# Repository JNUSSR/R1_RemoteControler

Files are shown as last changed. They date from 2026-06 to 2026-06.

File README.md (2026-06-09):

# R1遥控器

R1遥控器的工程仓库，包括PCB工程文件，代码工程文件，外壳文件，使用说明。

- 陶晶驰资料中心：http://wiki.tjc1688.com/
- 固件协议详见：[software/Romote_Controler/README.md](software/Romote_Controler/README.md)

## 更新

**2026-06**: 固件通信协议由自定义二进制帧迁移至 **MAVLink v2**，新增 Web 串口监视器。

```
software/Romote_Controler/
├── mavlink_xml/
│   ├── remote_control.xml   # MAVLink 协议定义 (MsgID=150)
│   └── index.html           # Web 串口监视器
├── Hardware/
│   ├── INTERRUPT/           # MAVLink 打包发送 (替代原 E28 协议)
│   └── mavlink/             # MAVLink C 库
└── README.md                # 详细说明
```

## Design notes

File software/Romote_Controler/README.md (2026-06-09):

# R1 遥控器 · 固件

本目录为 R1 遥控器的 STM32F405 固件工程。原通信协议为自定义二进制帧（E28 模块），现已迁移为标准 **MAVLink v2** 协议。

---

## MAVLink v2 通信协议

### 协议格式

使用 MAVLink v2 帧格式，通过 UART6 (E28 无线模块) 发送，115200/9600 baud 可配置。

### 自定义消息：REMOTE_CONTROL_STATE (MsgID = 150)

| 字段 | 类型 | 偏移 | 说明 |
|---|---|---|---|
| `kfs` | `uint32_t` | 0 | 梅林 KFS 按键矩阵 4×3，每元素 2 bit（值 0~3），共 24 bit |
| `encoder_0` | `int16_t` | 4 | 编码器 0 旋转位置值 |
| `encoder_1` | `int16_t` | 6 | 编码器 1 旋转位置值 |
| `encoder_2` | `int16_t` | 8 | 编码器 2 旋转位置值 |
| `encoder_3` | `int16_t` | 10 | 编码器 3 旋转位置值 |
| `move_0` | `int16_t` | 12 | 摇杆通道 0 移动量 |
| `move_1` | `int16_t` | 14 | 摇杆通道 1 移动量 |
| `move_2` | `int16_t` | 16 | 摇杆通道 2 移动量 |
| `move_3` | `int16_t` | 18 | 摇杆通道 3 移动量 |
| `mode` | `uint8_t` | 20 | 4 路模式拨码开关，bit0~bit3 对应 mode[0]~mode[3]（0=拨下，1=未拨下） |
| `act` | `uint8_t` | 21 | 6 动作独立位掩码：bit0~2=动作1~3(双稳态)，bit3~5=动作4~6(瞬时)，bit6~7保留 |
| `kfs_put` | `uint8_t` | 22 | R2 九宫格按键矩阵 2×3，每元素 1 bit（值 0~1），共 6 bit |

**Payload 大小**: 23 字节（MAVLink v2 会裁剪末尾零字节，实际传输长度可变 ≤23）

### 屏幕值到协议值的映射

**kfs（梅林矩阵 4×3）**:

| 屏幕上报 | 含义 | 减 1 后 | 协议存储 (2 bit) |
|---|---|---|---|
| 1 | 空 | 0 | `00` |
| 2 | R1 | 1 | `01` |
| 3 | R2 | 2 | `10` |
| 4 | 假 | 3 | `11` |

**kfs_put（九宫格 2×3）**:

| 屏幕上报 | 含义 | 减 1 后 | 协议存储 (1 bit) |
|---|---|---|---|
| 1 | 不放 | 0 | `0` |
| 2 | 放 | 1 | `1` |

**act（动作指令）**，6 个动作独立位掩码，互不干扰：

| Bit | 动作 | 含义 | 行为 |
|---|---|---|---|
| bit0 | 动作1 | 0=释放, 1=按下 | **双稳态**，不清零，状态持续上报 |
| bit1 | 动作2 | 0=释放, 1=按下 | **双稳态**，不清零，状态持续上报 |
| bit2 | 动作3 | 0=释放, 1=按下 | **双稳态**，不清零，状态持续上报 |
| bit3 | 动作4 | 0=空闲, 1=触发 | **瞬时**，发送后自动清零 |
| bit4 | 动作5 | 0=空闲, 1=触发 | **瞬时**，发送后自动清零 |
| bit5 | 动作6 | 0=空闲, 1=触发 | **瞬时**，发送后自动清零 |
| bit6~7 | — | 保留 | — |

> 屏幕上报原始值 `0xXY`（X=1~6, Y=1松开/2按下），固件解码后置位/清除 act_state 对应 bit。
> 可同时按下动作1和动作2，act=0x03，两个状态独立保留。

### KFS 位打包规则

```
kfs (uint32_t, bit[23:0]):
  kfs[0][0] → bit[ 1: 0]    kfs[2][0] → bit[13:12]
  kfs[0][1] → bit[ 3: 2]    kfs[2][1] → bit[15:14]
  kfs[0][2] → bit[ 5: 4]    kfs[2][2] → bit[17:16]
  kfs[1][0] → bit[ 7: 6]    kfs[3][0] → bit[19:18]
  kfs[1][1] → bit[ 9: 8]    kfs[3][1] → bit[21:20]
  kfs[1][2] → bit[11:10]    kfs[3][2] → bit[23:22]
  bit[31:24] → 保留

kfs_put (uint8_t, bit[5:0]):
  kfs_put[0][0] → bit[0]    kfs_put[1][0] → bit[3]
  kfs_put[0][1] → bit[1]    kfs_put[1][1] → bit[4]
  kfs_put[0][2] → bit[2]    kfs_put[1][2] → bit[5]
  bit[7:6] → 保留
```

### 发送条件

- **硬守卫**: E28 模块空闲 (PB15 引脚 = HIGH)
- **软守卫**: STM32 UART6 DMA 发送就绪 (`huart6.gState == HAL_UART_STATE_READY`)
- **模式条件**: 仅当 `mode[0]` 拨下（低电平）时发送

### 发送后消费

- **kfs / kfs_put**: 保持屏幕上报的最新值，**发送后不清零**，持续上报当前状态
- **act**: 固件内部维护 `act_state` 位掩码（static 变量）
  - 屏幕上报 `0xXY` 事件 → 解码 ID/状态 → 置位/清除 act_state 对应 bit → 屏幕 `act` 清零消费
  - 动作 1~3 (bit0~2)：**双稳态**，按下置位、松开清零，不清除
  - 动作 4~6 (bit3~5)：**瞬时**，按下置位，发送后 `act_state &= ~0x38` 自动清零
  - 6 个动作独立保存，同时按下多个互不干扰

---

## 目录结构

```
software/Romote_Controler/
├── Core/                    # STM32CubeMX 生成的核心代码
│   ├── Inc/
│   │   └── main.h
│   └── Src/
│       ├── main.c           # 主程序，printf → USART2 串口屏
│       ├── syscalls.c       # newlib/picolibc 系统调用 (printf 重定向)
│       └── ...
├── Hardware/
│   ├── E28/                 # E28 模块旧驱动 (已弃用，保留参考)
│   │   └── e28.c
│   ├── INTERRUPT/           # 中断处理
│   │   ├── interrupt.c      # TIM5 中断回调 + MAVLink 打包发送
│   │   └── interrupt.h
│   ├── SCREEN/              # 触摸屏驱动 (USART2)
│   │   ├── screen.c         # 屏幕数据解析 (HAL_UARTEx_RxEventCallback)
│   │   └── screen.h
│   ├── ENCODER/             # 编码器读取
│   ├── ADC_GET/             # ADC 摇杆数据采集
│   ├── INIT/                # 系统初始化
│   └── mavlink/             # MAVLink C 库 (从 XML 生成)
│       ├── mavlink_types.h
│       ├── mavlink_helpers.h
│       └── remote_control/
│           ├── mavlink.h
│           └── mavlink_msg_remote_control_state.h
├── mavlink_xml/
│   ├── remote_control.xml   # MAVLink 协议定义 (dialect XML)
│   └── index.html           # Web 串口监视器 (Chrome/Edge)
├── CMakeLists.txt
└── README.md
```

---

## 更新日志

### 2026-06 — MAVLink v2 协议迁移

| 变更 | 文件 | 说明 |
|---|---|---|
| 新增 | `mavlink_xml/remote_control.xml` | MAVLink v2 协议定义，消息 ID=150 |
| 新增 | `mavlink_xml/index.html` | 网页版 MAVLink 串口监视器 (Web Serial API) |
| 新增 | `Hardware/mavlink/` | 从 XML 生成的 MAVLink C 库 |
| 修改 | `Hardware/INTERRUPT/interrupt.c` | 新增 `MAVLink_Pack_And_Send()` 替代原 `Pack_And_Send_E28()` |
| 修改 | `Hardware/INTERRUPT/interrupt.h` | 更新依赖：`e28.h` → `mavlink.h` |
| 修改 | `Core/Src/main.c` | 新增 `__io_putchar()` 修复 GCC 下 printf 重定向 |

**数据精度优化**:
- `kfs[4][3]`: 12 字节 → 4 字节（uint32_t 位压缩，每元素 2 bit）
- `kfs_put[2][3]`: 6 字节 → 1 字节（uint8_t 位压缩，每元素 1 bit）
- `mode[4]`: 新增，1 字节（4 bit）
- 总 payload: 37 字节 → **23 字节**

**关键修复**:
- 修复 DMA 发送缓冲区栈内存生命周期问题 (改为 static/全局)
- 修复 `mavlink_message_t`(~295B) 在 ISR 栈分配导致栈溢出
- 修复 GCC/newlib 工具链 `printf` 缺少 `__io_putchar()` 实现

---

## Web 监视器使用

1. 用 Chrome/Edge 浏览器打开 `mavlink_xml/index.html`
2. 选择对应 COM 口和波特率，点击「连接串口」
3. 遥控器 `mode[0]` 拨下后，页面实时更新所有数据

---

## 构建

```bash
cd software/Romote_Controler
cmake -B build -G "Unix Makefiles"  # 或 Ninja
cmake --build build
```

工具链: `arm-none-eabi-gcc` (STM32CubeIDE / GNU Arm Embedded Toolchain)

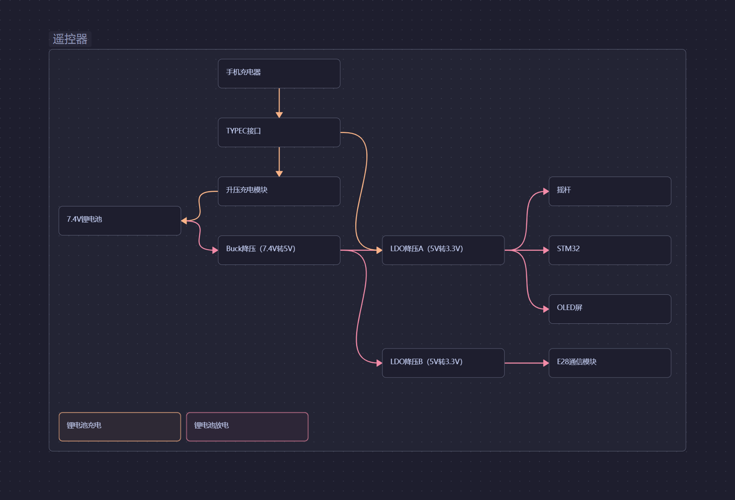
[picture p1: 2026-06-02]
hardware/R1遥控器电路框架.png

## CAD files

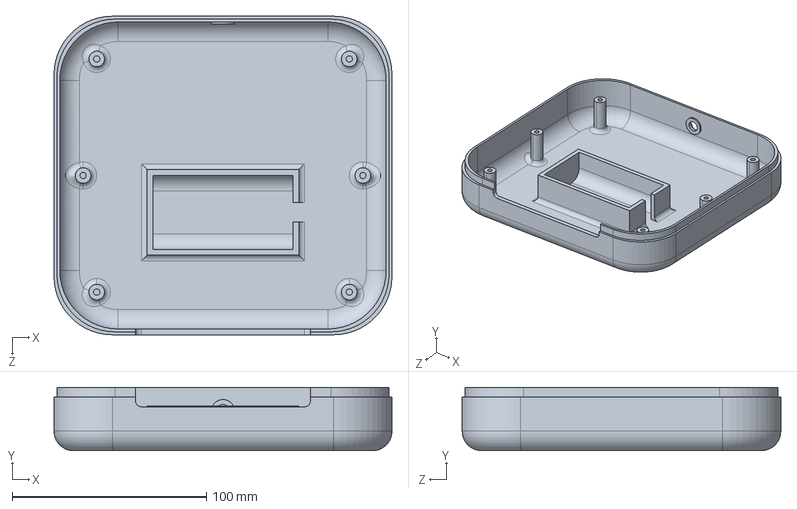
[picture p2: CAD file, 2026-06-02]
structure/外壳/遥控器外壳底板.STEP
174.0 x 32.6 x 164.0 mm

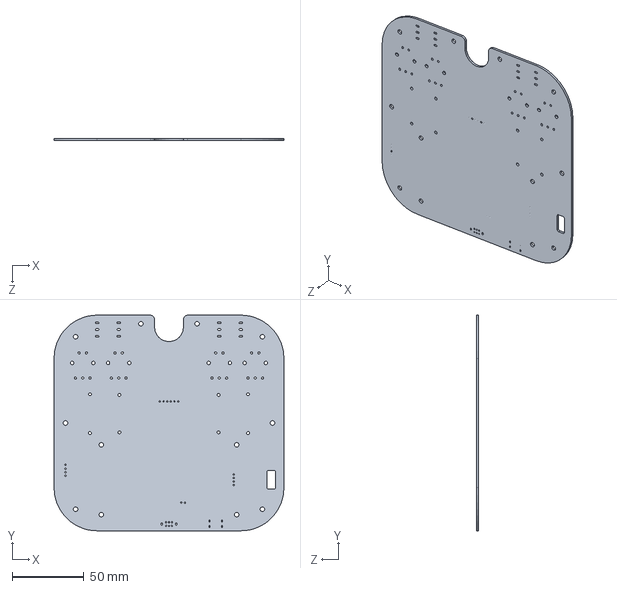
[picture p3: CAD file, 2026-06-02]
structure/外壳/遥控器PCB.SLDPRT
160.0 x 150.0 x 1.60 mm

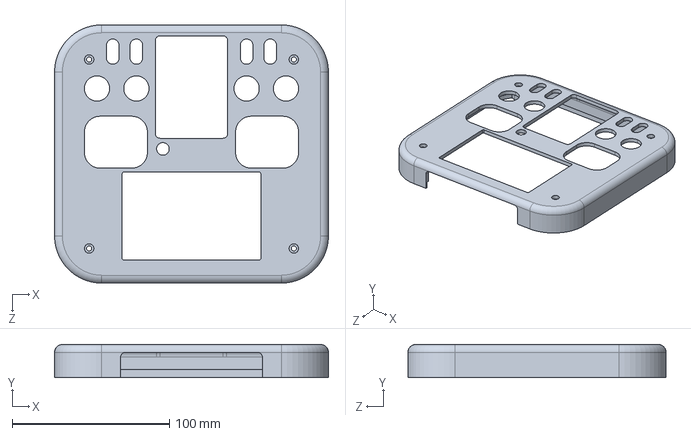
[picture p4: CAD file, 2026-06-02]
structure/外壳/遥控器外壳顶板.STEP
174.0 x 21.0 x 164.0 mm

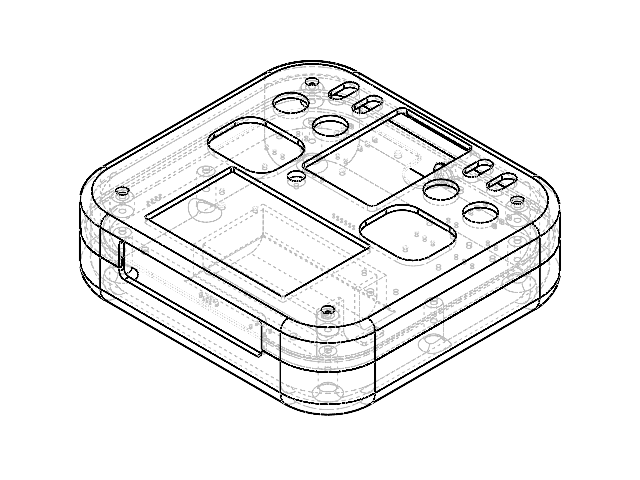
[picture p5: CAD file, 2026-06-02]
structure/外壳/遥控器装配.SLDASM
遥控器外壳底板
遥控器外壳顶板
遥控器PCB

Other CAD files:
structure/外壳/遥控器外壳底板.SLDPRT
structure/外壳/遥控器外壳顶板.SLDPRT

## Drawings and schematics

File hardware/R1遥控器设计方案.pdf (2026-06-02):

## R1遥控器设计方案 一、操作方案

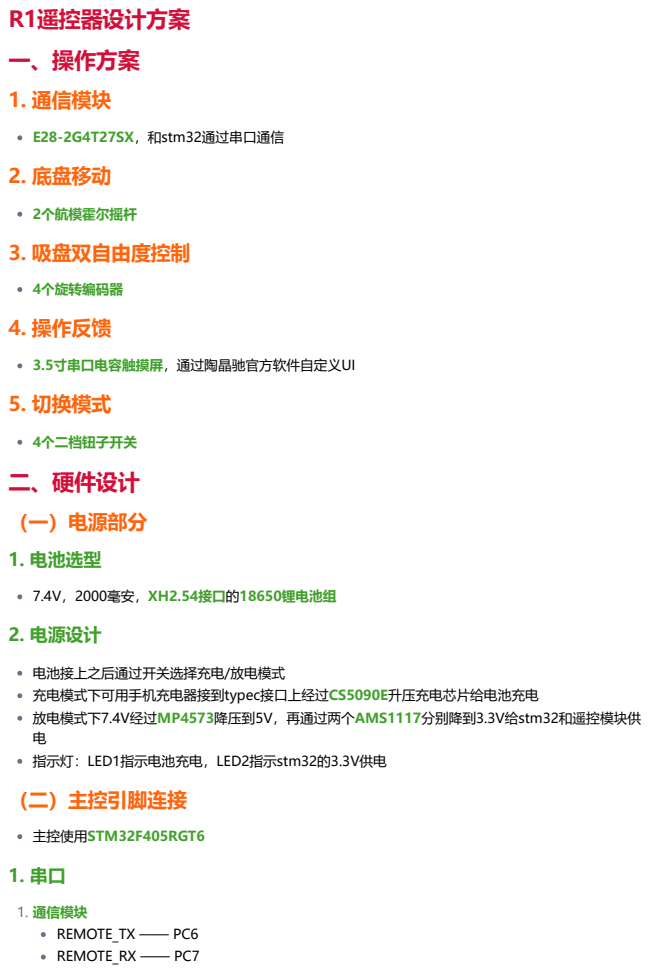
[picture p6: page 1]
1. 通信模块; 2. 底盘移动; 3. 吸盘双自由度控制; 4. 操作反馈; 5. 切换模式; 二、硬件设计; （一）电源部分; 1. 电池选型; 2. 电源设计; （二）主控引脚连接; E28-2G4T27SX，和stm32通过串口通信; 2个航模霍尔摇杆; 4个旋转编码器; 3.5寸串口电容触摸屏，通过陶晶驰官方软件自定义UI; 4个二档钮子开关; 7.4V，2000毫安，XH2.54接口的18650锂电池组; 电池接上之后通过开关选择充电/放电模式 充电模式下可用手机充电器接到typec接口上经过CS5090E升压充电芯片给电池充电 放电模式下7.4V经过MP4573降压到5V，再通过两个AMS1117分别降到3.3V给stm32和遥控模块供 电 指示灯：LED1指示电池充电，LED2指示stm32的3.3V供电; 主控使用STM32F405RGT6; 1. 通信模块 REMOTE_TX —— PC6 REMOTE_RX —— PC7

### 2. ADC

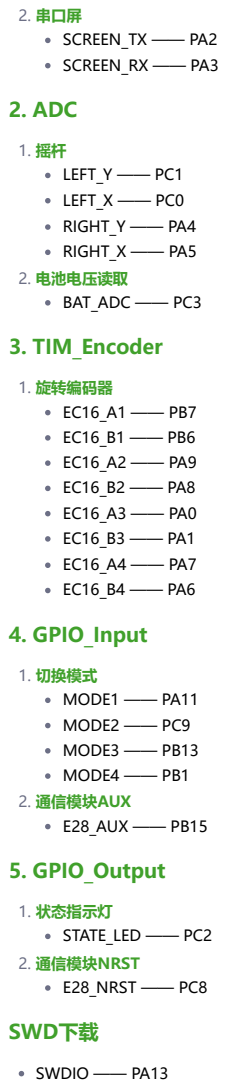
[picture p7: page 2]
3. TIM_Encoder; 4. GPIO_Input; 5. GPIO_Output; SWD下载; 2. 串口屏 SCREEN_TX —— PA2 SCREEN_RX —— PA3; 1. 摇杆 LEFT_Y —— PC1 LEFT_X —— PC0 RIGHT_Y —— PA4 RIGHT_X —— PA5 2. 电池电压读取 BAT_ADC —— PC3; 1. 旋转编码器 EC16_A1 —— PB7 EC16_B1 —— PB6 EC16_A2 —— PA9 EC16_B2 —— PA8 EC16_A3 —— PA0 EC16_B3 —— PA1 EC16_A4 —— PA7 EC16_B4 —— PA6; 1. 切换模式 MODE1 —— PA11 MODE2 —— PC9 MODE3 —— PB13 MODE4 —— PB1 2. 通信模块AUX E28_AUX —— PB15; 1. 状态指示灯 STATE_LED —— PC2 2. 通信模块NRST E28_NRST —— PC8; SWDIO —— PA13

SWCLK —— PA14

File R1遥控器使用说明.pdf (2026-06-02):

## R1遥控器使用说明 一、遥控器

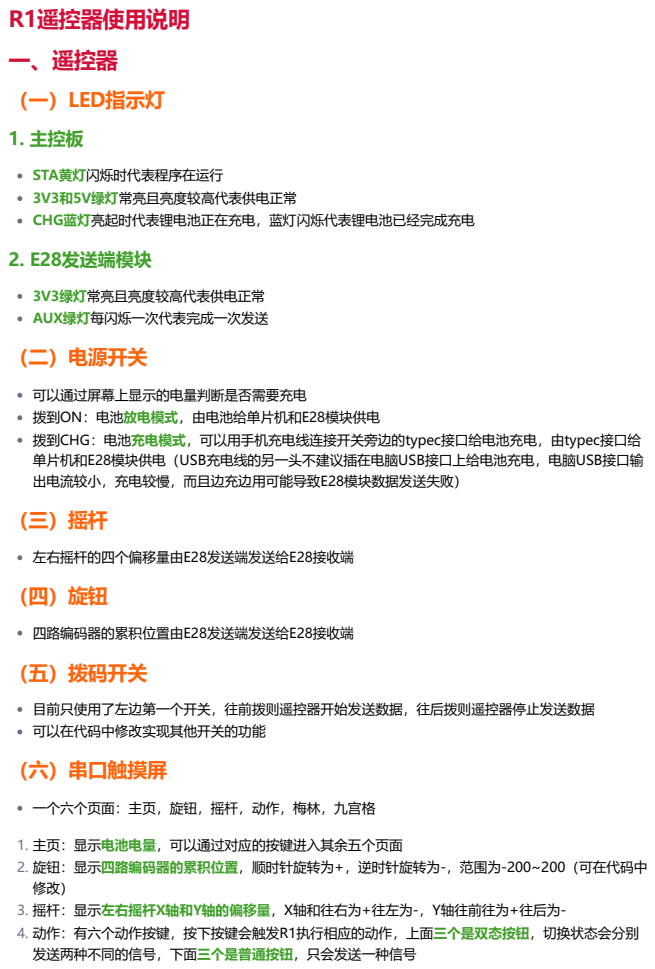
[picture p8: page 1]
（一）LED指示灯; 1. 主控板; 2. E28发送端模块; （二）电源开关; （五）拨码开关; STA黄灯闪烁时代表程序在运行 3V3和5V绿灯常亮且亮度较高代表供电正常 CHG蓝灯亮起时代表锂电池正在充电，蓝灯闪烁代表锂电池已经完成充电; 3V3绿灯常亮且亮度较高代表供电正常 AUX绿灯每闪烁一次代表完成一次发送; 左右摇杆的四个偏移量由E28发送端发送给E28接收端; 四路编码器的累积位置由E28发送端发送给E28接收端

可以通过屏幕上显示的电量判断是否需要充电
拨到ON：电池放电模式，由电池给单片机和E28模块供电
拨到CHG：电池充电模式，可以用手机充电线连接开关旁边的typec接口给电池充电，由typec接口给
单片机和E28模块供电（USB充电线的另一头不建议插在电脑USB接口上给电池充电，电脑USB接口输
出电流较小，充电较慢，而且边充边用可能导致E28模块数据发送失败）

目前只使用了左边第一个开关，往前拨则遥控器开始发送数据，往后拨则遥控器停止发送数据
可以在代码中修改实现其他开关的功能
（六）串口触摸屏

一个六个页面：主页，旋钮，摇杆，动作，梅林，九宫格

1. 主页：显示电池电量，可以通过对应的按键进入其余五个页面
2. 旋钮：显示四路编码器的累积位置，顺时针旋转为+，逆时针旋转为-，范围为-200~200（可在代码中
3. 摇杆：显示左右摇杆X轴和Y轴的偏移量，X轴和往右为+往左为-，Y轴往前往为+往后为-
4. 动作：有六个动作按键，按下按键会触发R1执行相应的动作，上面三个是双态按钮，切换状态会分别
发送两种不同的信号，下面三个是普通按钮，只会发送一种信号

## （七）程序烧录

## 二、E28接收端

5. 梅林：用于操作手录入并发送梅林区KFS位置信息，一共四行三列12个按键，每个按键分别有四种状态 （空/R1/R2/假），按下确认键后KFS的位置信息会发送给R1
6. 九宫格：用于选择操作手想要将R2的KFS放置在九宫格上中的具体位置，一共两行三列6个按键，每个 按键有两种状态（空/放），按下确认键后KFS的放置信息会发送给R1

主控芯片烧录：打开遥控器外壳后可以看到SWD接口在板子的右下角 串口屏烧录：使用陶晶驰官方软件打开并修改串口屏工程文件之后，将串口屏接口线拔下后接到USB转 TTL模块上插入电脑USB接口，在软件中选择 “下载-联机并开始下载” 即可

电源：通过XT30用24V或12V供电
信号：AUX和NRST由排针引出，RX，TX，GND由排针和GH1.25接口引出 3V3绿灯常亮且亮度较高代表供电正常
AUX绿灯每闪烁一次代表完成一次接收

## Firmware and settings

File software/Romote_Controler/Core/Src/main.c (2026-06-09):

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
/* Includes ------------------------------------------------------------------*/
#include "main.h"
#include "adc.h"
#include "dma.h"
#include "tim.h"
#include "usart.h"
#include "gpio.h"

/* USER CODE BEGIN Includes */
#include "init.h"
/* USER CODE END Includes */


/* USER CODE BEGIN PV */
/* 全局共享变量说明：
 * - encoder: 四路编码器累积位置（来自 encoder 模块）
 * - move: 四路摇杆/移动量（来自 adc_get 模块）
 * - battery_voltage: 过滤后的电池电压（单位 V）
 * - battery_percent: 换算后的电池百分比（0-100）
 */
extern int16_t encoder[4];
extern int16_t move[4];
extern float battery_voltage;
extern uint8_t battery_percent;
/* USER CODE END PV */

void SystemClock_Config(void);
/* USER CODE BEGIN 0 */
/**
 * 功能说明：将 printf 输出重定向到 USART2（阻塞式发送）
 * 参数：
 *  - ch: 要发送的字符
 *  - f: 目标 FILE*（未使用）
 * 返回值：
 *  - 返回写入的字符
 */
int fputc(int ch, FILE *f)
{
    HAL_UART_Transmit(&huart2, (uint8_t *)&ch, 1, 0xFFFF);
    return ch;
}

/**
 * 功能说明：GCC/newlib/picolibc 的 printf 重定向底层函数。
 *          printf → _write() → __io_putchar() 这条链最终到达这里。
 *          与 fputc 不同的是，fputc 仅对 Keil/MDK 工具链有效，
 *          GCC 工具链必须实现 __io_putchar。
 */
int __io_putchar(int ch)
{
    HAL_UART_Transmit(&huart2, (uint8_t *)&ch, 1, 0xFFFF);
    return ch;
}
/* USER CODE END 0 */

/**
  * @brief  The application entry point.
  * @retval int
  */
int main(void)
{

  /* MCU Configuration--------------------------------------------------------*/

  /* Reset of all peripherals, Initializes the Flash interface and the Systick. */
  HAL_Init();

  /* Configure the system clock */
  SystemClock_Config();

  /* Initialize all configured peripherals */
  MX_GPIO_Init();
  MX_DMA_Init();
  MX_TIM2_Init();
  MX_ADC1_Init();
  MX_USART6_UART_Init();
  MX_TIM1_Init();
  MX_TIM3_Init();
  MX_TIM4_Init();
  MX_TIM5_Init();
  MX_USART2_UART_Init();
  /* USER CODE BEGIN 2 */
  /* 初始化外设与 DMA/中断等（在 Init 中实现） */
  Init();
  /* USER CODE END 2 */

  /* Infinite loop */
  /* USER CODE BEGIN WHILE */
  while (1)
  {
    /* 主循环：将状态通过串口发给触摸屏显示。注意：printf 可能是阻塞的，
   * 如果对实时性敏感，应将显示更新移到低优先级任务或采用 DMA 非阻塞发送。
   */
    /* 串口屏显示 */
    // 编码器值
    printf("page1.n0.val=%d\xff\xff\xff", encoder[0]);
    printf("page1.n1.val=%d\xff\xff\xff", encoder[1]);
    printf("page1.n2.val=%d\xff\xff\xff", encoder[2]);
    printf("page1.n3.val=%d\xff\xff\xff", encoder[3]);

    // 摇杆值
    printf("page2.n0.val=%d\xff\xff\xff", move[0]);
    printf("page2.n1.val=%d\xff\xff\xff", move[1]);
    printf("page2.n2.val=%d\xff\xff\xff", move[2]);
    printf("page2.n3.val=%d\xff\xff\xff", move[3]);

    // 电池电量值
    printf("Main.n0.val=%d\xff\xff\xff", battery_percent);
    printf("Main.j0.val=%d\xff\xff\xff", battery_percent);
  }
    /* USER CODE END WHILE */

}

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


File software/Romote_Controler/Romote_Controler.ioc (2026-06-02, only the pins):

Mcu.UserName=STM32F405RGTx
PA0-WKUP.Signal=S_TIM2_CH1_ETR
PA1.Signal=S_TIM2_CH2
PA11.Signal=GPIO_Input
PA13.Signal=SYS_JTMS-SWDIO
PA14.Signal=SYS_JTCK-SWCLK
PA2.Signal=USART2_TX
PA3.Signal=USART2_RX
PA4.Signal=ADCx_IN4
PA5.Signal=ADCx_IN5
PA6.Signal=S_TIM3_CH1
PA7.Signal=S_TIM3_CH2
PA8.Signal=S_TIM1_CH1
PA9.Signal=S_TIM1_CH2
PB1.Signal=GPIO_Input
PB13.Signal=GPIO_Input
PB15.Signal=GPIO_Input
PB6.Signal=S_TIM4_CH1
PB7.Signal=S_TIM4_CH2
PC0.Signal=ADCx_IN10
PC1.Signal=ADCx_IN11
PC2.Signal=GPIO_Output
PC3.Signal=ADCx_IN13
PC6.Signal=USART6_TX
PC7.Signal=USART6_RX
PC8.Signal=GPIO_Output
PC9.Signal=GPIO_Input
PH0-OSC_IN.Signal=RCC_OSC_IN
PH1-OSC_OUT.Signal=RCC_OSC_OUT

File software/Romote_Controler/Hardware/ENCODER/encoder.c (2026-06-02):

#include "encoder.h"

/* encoder: 存储四路编码器的累积位置（带符号，范围受限于 ±200） */
int16_t encoder[4] = {0};
/* count_last: 记录每路编码器上次读取的硬件计数（uint16_t，直接来自 TIM CNT 寄存器） */
uint16_t count_last[4] = {0};

/**
 * 功能说明：读取编码器相对于上次的脉冲增量，自动处理 16-bit 回绕
 * 参数：
 *  - htim: 指向对应编码器计数器的 TIM_HandleTypeDef
 *  - last_count: 指向保存上次计数的变量，函数会更新该变量
 * 返回值：
 *  - int16_t: 与上次读取相比的计数增量（正/负表示旋转方向）
 */
int16_t Get_Encoder_Delta(TIM_HandleTypeDef *htim, uint16_t *last_count)
{
    uint16_t curr_count = __HAL_TIM_GET_COUNTER(htim);
    int16_t delta = (int16_t)(curr_count - *last_count);
    *last_count = curr_count;
    return delta;
}

/**
 * 功能说明：更新全局 encoder[] 数组的值，应被周期性调用（例如在 TIM 回调中）
 * 参数：无
 * 返回值：无
 */
void Get_Encoder(void)
{
	/* 编码器增量计算与累加 */
	int16_t delta1 = Get_Encoder_Delta(&htim4, &count_last[0]);
	if (delta1 != 0) 
	{
		encoder[0] -= delta1;
		if(encoder[0] >=  200) encoder[0] = 200;
		if(encoder[0] <= -200) encoder[0] = -200;
	}
	int16_t delta2 = Get_Encoder_Delta(&htim1, &count_last[1]);
	if (delta2 != 0) 
	{
		encoder[1] -= delta2;
		if(encoder[1] >=  200) encoder[1] = 200;
		if(encoder[1] <= -200) encoder[1] = -200;
	}
	int16_t delta3 = Get_Encoder_Delta(&htim2, &count_last[2]);
	if (delta3 != 0) 
	{
		encoder[2] += delta3;
		if(encoder[2] >=  200) encoder[2] = 200;
		if(encoder[2] <= -200) encoder[2] = -200;
	}
	int16_t delta4 = Get_Encoder_Delta(&htim3, &count_last[3]);
	if (delta4 != 0) 
	{
		encoder[3] -= delta4;
		if(encoder[3] >=  200) encoder[3] = 200;
		if(encoder[3] <= -200) encoder[3] = -200;
	}
}

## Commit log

2026-06-02 上传了R1遥控器的代码文件，PCB文件，外壳文件，使用说明
    [遥控器PCB.SLDPRT, 遥控器外壳底板.SLDPRT, 遥控器外壳底板.STEP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]
2026-06-09 feat: migrate to MAVLink v2 protocol, add web monitor, fix printf redirect
    - Add MAVLink v2 dialect XML for REMOTE_CONTROL_STATE (MsgID=150)
    - Replace custom E28 binary protocol with MAVLink in interrupt handler
    - Bit-pack kfs (12B→4B) and kfs_put (6B→1B) for payload efficiency
    - Add Web Serial API monitor page (mavlink_xml/index.html)
    - Add generated MAVLink C library headers for STM32
    - Fix DMA buffer stack lifetime (local→static/global)
    - Fix mavlink_message_t stack allocation (~295B) in ISR context
    - Fix GCC/newlib printf redirect: add __io_putchar() alongside fputc()
    - Update README with protocol documentation
    [interrupt.c, main.c]
2026-06-09 fix: JS CRC-16 8-bit truncation and payload length validation
    - Add tmp &= 0xFF to match C uint8_t truncation in CRC-16/MCRF4XX
    - Add len >= 23 guard before parsing REMOTE_CONTROL_STATE payload
    - Prevents 'Cannot read properties of undefined' when frame too short
2026-06-09 feat: redesign act encoding with press/hold/release state machine
    Act byte encoding 0xXY: X=action_id(1-6), Y=state(1=release,2=press)
    - Actions 1-3: press-and-hold — keep transmitting until release
    - Actions 4-6: one-shot press — clear after single transmission
    - MAVLink_Pack_And_Send now takes act_val pointer for smart clear
    - Web monitor decodes and displays action name/state
    [interrupt.c]
2026-06-09 fix: subtract 1 from screen kfs/kfs_put values before bit-packing
    Screen reports kfs as 1-4 and kfs_put as 1-2, but protocol expects
    0-3 (2-bit) and 0-1 (1-bit). Subtract 1 before masking to correct.
    [interrupt.c]
2026-06-09 docs: update README with screen-to-protocol value mappings
    Document kfs (1-4→0-3), kfs_put (1-2→0-1), act (0xXY encoding)
    with press/hold/release state machine behavior.
2026-06-09 fix: prevent uint8_t underflow when kfs/kfs_put values are 0
    After memset clears arrays, value=0 caused (0-1)&0x03=3 and
    (0-1)&0x01=1. Now only subtracts 1 when value > 0.
    [interrupt.c]
2026-06-09 refactor: kfs/kfs_put persist, act 1-3 dual-state bistable
    - kfs and kfs_put no longer cleared after send, keep latest screen state
    - Act actions 1-3: changed to bistable (pressed=keep, released→0x00 persist)
    - Act actions 4-6: remain one-shot trigger (clear after send)
    - Remove memset calls from TIM5 callback
    [interrupt.c]
2026-06-09 refactor: act uses 6-bit independent bitmask, each action isolated
    Act byte redesigned from single-action 0xXY encoding to 6-bit mask:
    - bit0-2: actions 1-3 bistable (0=release, 1=press), persist
    - bit3-5: actions 4-6 momentary (0=idle, 1=triggered), auto-clear
    - Multiple actions can be active simultaneously (e.g. 0x03 = A1+A2)
    - Firmware maintains act_state static variable, decodes screen events
    - Web monitor displays all 6 action indicators independently
    [interrupt.c]

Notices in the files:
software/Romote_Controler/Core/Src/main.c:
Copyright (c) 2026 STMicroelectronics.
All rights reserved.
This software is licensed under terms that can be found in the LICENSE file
